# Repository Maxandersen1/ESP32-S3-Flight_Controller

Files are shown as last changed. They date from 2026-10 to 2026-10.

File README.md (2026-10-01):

# ESP32-S3 Custom Flight Controller

A custom-designed drone flight controller built from the ground up around the ESP32-S3 microcontroller. This project is a work-in-progress, covering everything from custom PCB design in KiCad to low-level sensor drivers and Web Serial 3D visualization.

## Hardware Features
- **Microcontroller**: ESP32-S3
- **IMU**: Bosch BMI088 (6-axis accelerometer & gyroscope) via SPI
- **Barometer**: Bosch BMP388 via I2C
- **PCB**: Custom designed in KiCad, hand-soldered SMD components.

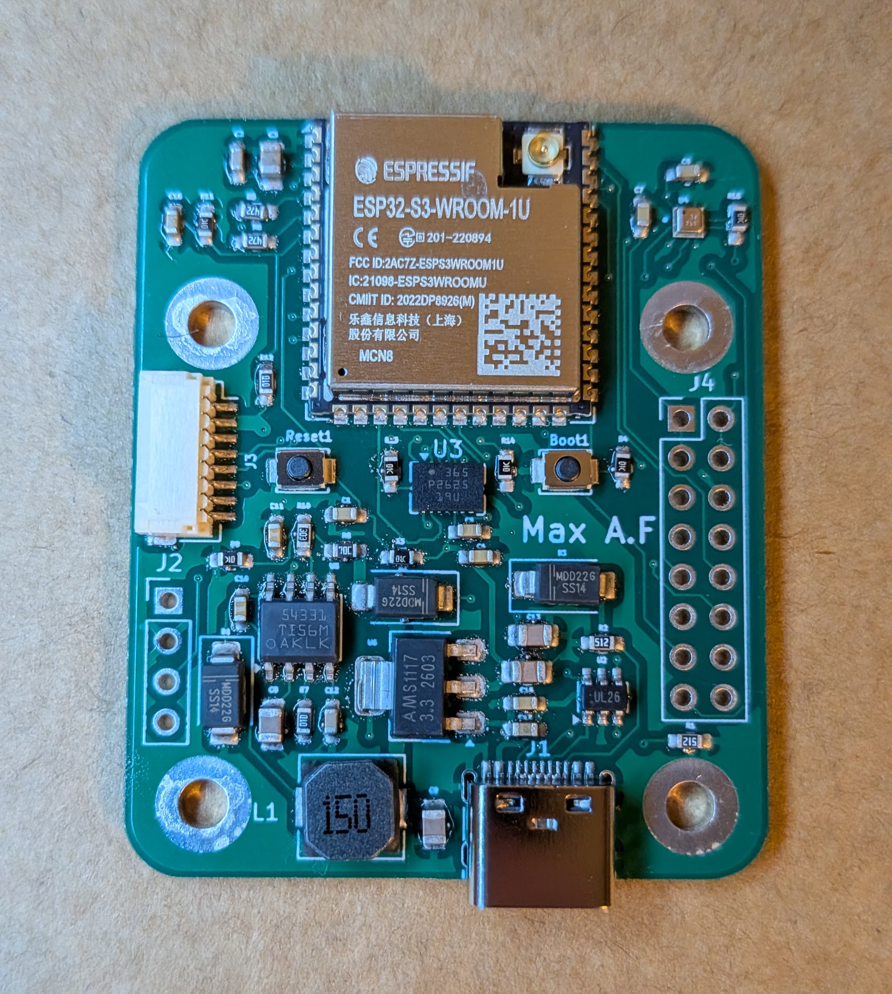
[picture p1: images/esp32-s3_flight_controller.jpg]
Mitt kretskort


## Software / Firmware
The firmware is written in C++ (Arduino framework) and features:
- **Raw SPI Communication**: Bypasses bloated libraries to communicate directly with the BMI088 registers, resolving complex ESP32 HAL macro conflicts.
- **Sensor Fusion**: Implements a custom Complementary Filter combining high-speed gyro data with accelerometer gravity vectors for stable, drift-free Pitch and Roll calculation.
- **Barometric Altimeter**: Features an auto-zeroing routine on startup to establish local ground-level pressure before calculating relative altitude in meters.

## 3D Web Visualizer
Included in the `tools/` directory is a custom HTML5/Three.js 3D drone visualizer. 
It uses the modern **Web Serial API** to connect directly to the flight controller via USB (no servers required) and renders the drone's orientation in real-time at 60fps based on the live IMU telemetry.

## Directory Structure
- `hardware/`: KiCad schematics and PCB layout files.
- `firmware/FlightController/`: The main C++ Arduino sketch containing sensor drivers and mathematical filters.
- `tools/`: Contains `3D_Viewer.html` (Double-click to open in a modern browser).

## Roadmap / To-Do
- [x] PCB Design & Assembly
- [x] I2C & SPI Bring-up
- [x] Raw IMU & Barometer Data Extraction
- [x] Sensor Fusion (Complementary Filter)
- [x] Real-time 3D Visualization
- [ ] PID Controller Implementation
- [ ] ESC Motor Output (DSHOT/PWM)
- [ ] Radio Receiver Integration (ExpressLRS/Crossfire)

*Hardware designed from scratch by Max. Firmware and 3D visualization developed using AI-assisted pair programming.*

## Hardware design process
###Schematic

KiCad Schematic

###PCB-layout

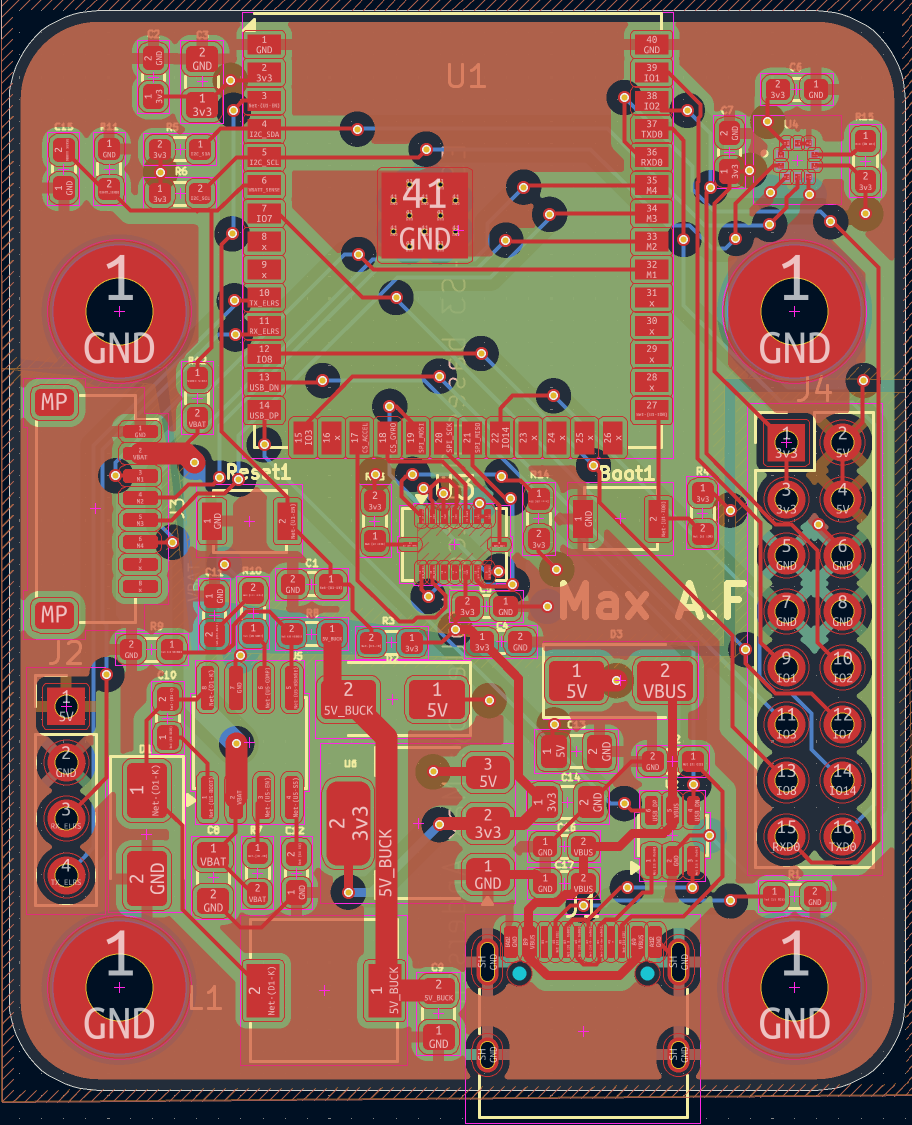
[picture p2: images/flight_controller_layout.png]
KiCad layout


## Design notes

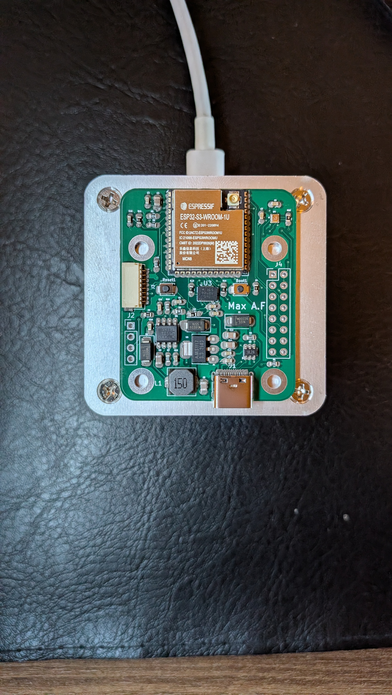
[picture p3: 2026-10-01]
images/hot_plate.jpg

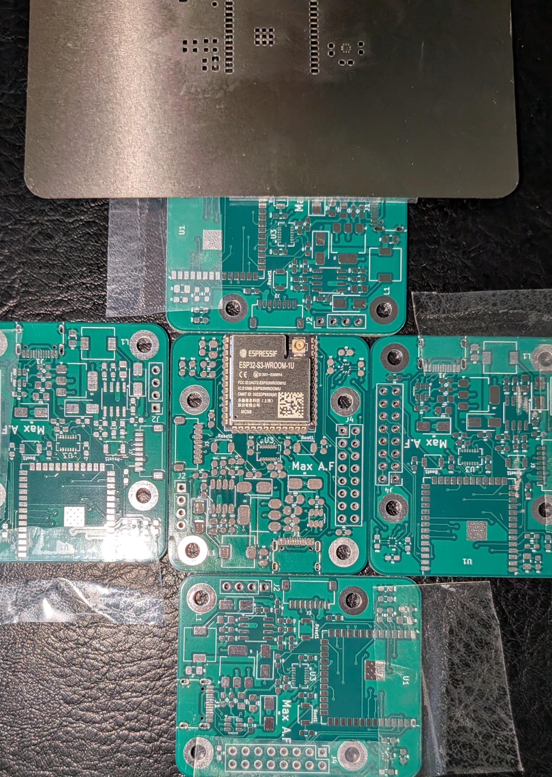
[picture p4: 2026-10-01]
images/esp_added.jpg

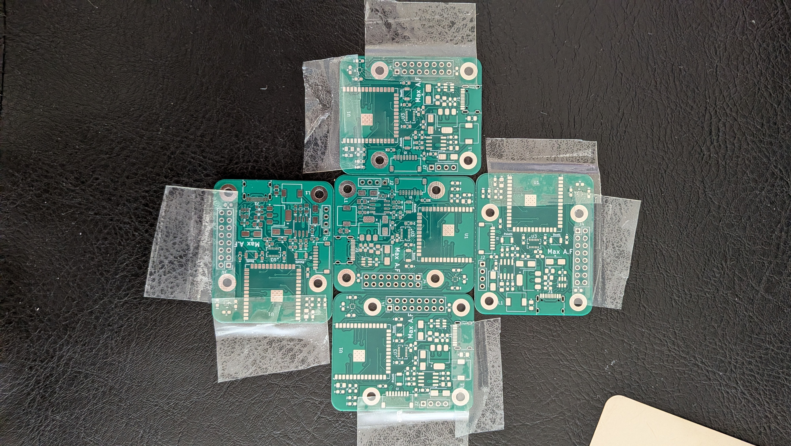
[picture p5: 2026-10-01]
images/taped_pcb.jpg

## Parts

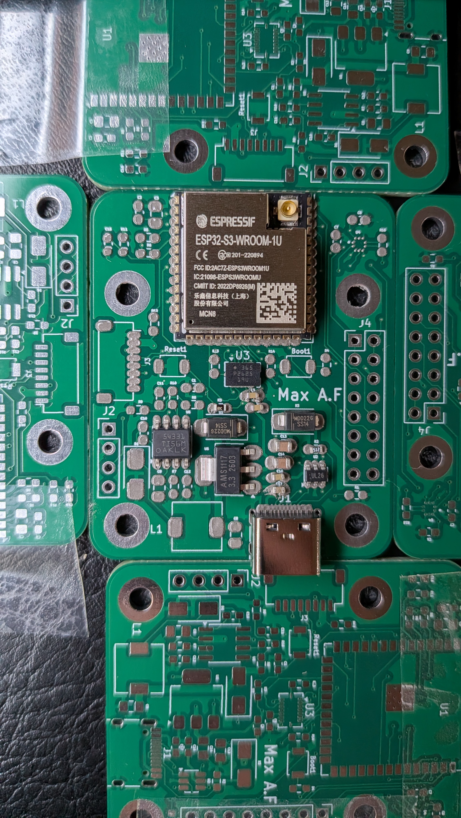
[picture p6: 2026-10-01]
images/components_added1.jpg

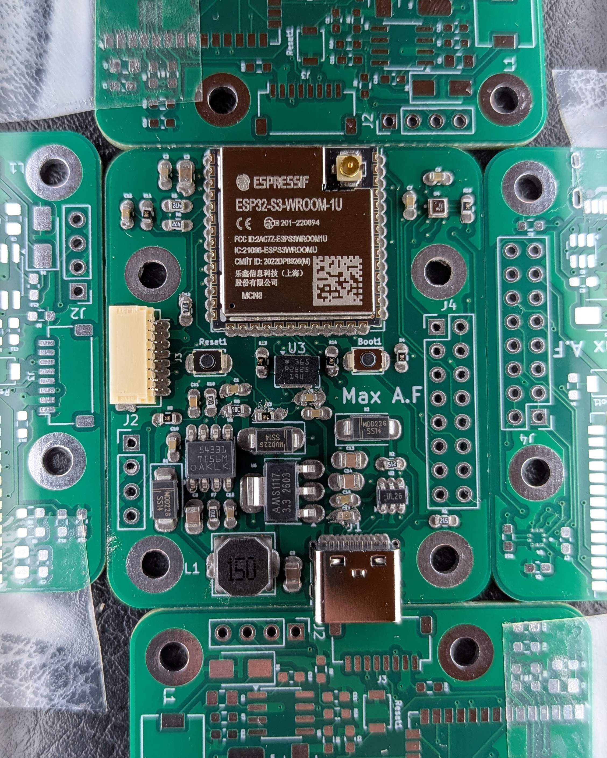
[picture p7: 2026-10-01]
images/all_components_added.jpg

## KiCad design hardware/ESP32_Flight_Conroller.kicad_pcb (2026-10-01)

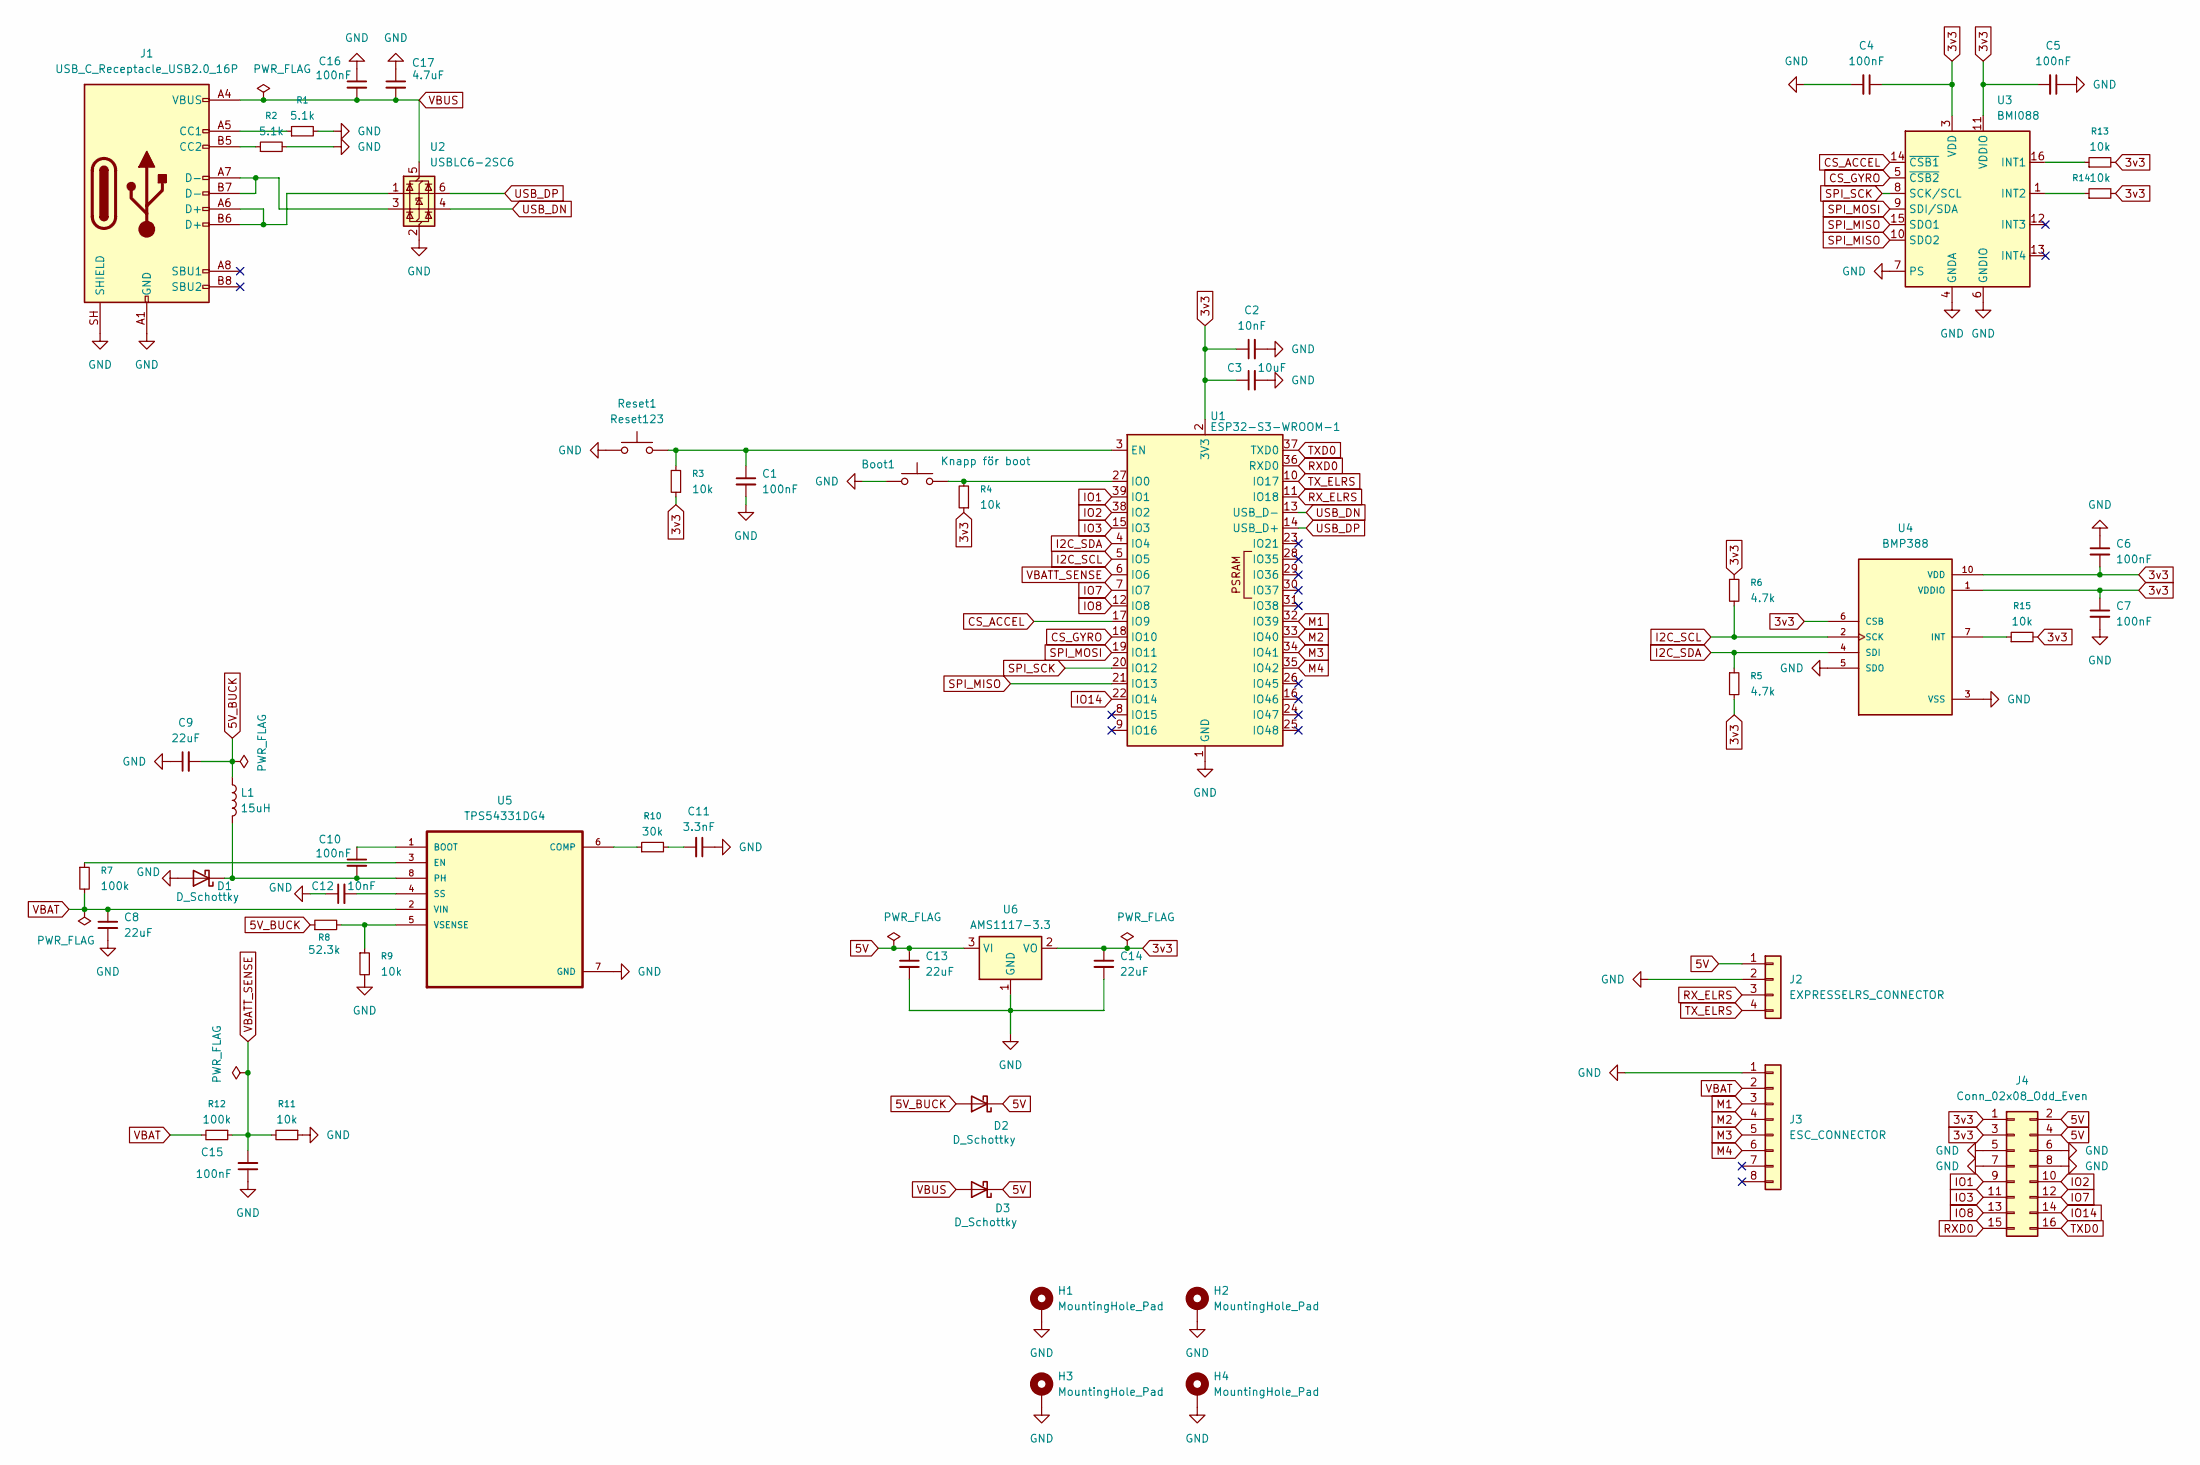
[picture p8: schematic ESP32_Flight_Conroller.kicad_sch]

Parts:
Boot1: Knapp för boot; SW_SPST_B3U-1000P
C1, C4, C5, C6, C7, C10, C15, C16: 100nF; C_0603_1608Metric_Pad1.08x0.95mm_HandSolder
C2, C12: 10nF; C_0603_1608Metric_Pad1.08x0.95mm_HandSolder
C3: 10uF; C_0805_2012Metric_Pad1.18x1.45mm_HandSolder
C8, C9, C13, C14: 22uF; C_0805_2012Metric_Pad1.18x1.45mm_HandSolder
C11: 3.3nF; C_0603_1608Metric_Pad1.08x0.95mm_HandSolder
C17: 4.7uF; C_0603_1608Metric_Pad1.08x0.95mm_HandSolder
D1, D2, D3: D_Schottky; D_SMA
H1, H2, H3, H4: MountingHole_Pad; MountingHole_3mm_Pad
J1: USB_C_Receptacle_USB2.0_16P; USB_C_Receptacle_HRO_TYPE-C-31-M-12
J2: EXPRESSELRS_CONNECTOR; PinHeader_1x04_P2.54mm_Vertical
J3: ESC_CONNECTOR; JST_SH_SM08B-SRSS-TB_1x08-1MP_P1.00mm_Horizontal
J4: Conn_02x08_Odd_Even; PinHeader_2x08_P2.54mm_Vertical
L1: 15uH; L_6.3x6.3_H3
R1, R2: 5.1k; R_0603_1608Metric_Pad0.98x0.95mm_HandSolder
R3, R4, R9, R11, R13, R14, R15: 10k; R_0603_1608Metric_Pad0.98x0.95mm_HandSolder
R5, R6: 4.7k; R_0603_1608Metric_Pad0.98x0.95mm_HandSolder
R7, R12: 100k; R_0603_1608Metric_Pad0.98x0.95mm_HandSolder
R8: 52.3k; R_0603_1608Metric_Pad0.98x0.95mm_HandSolder
R10: 30k; R_0603_1608Metric_Pad0.98x0.95mm_HandSolder
Reset1: Reset123; SW_SPST_B3U-1000P
U1: ESP32-S3-WROOM-1; ESP32-S3-WROOM-1U
U2: USBLC6-2SC6; SOT-23-6
U3: BMI088; Bosch_LGA-16_4.5x3mm_P0.5mm_LayoutBorder7x1y_ClockwisePinNu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
U4: BMP388; XDCR_BMP388; PARTREV 1.7
U5: TPS54331DG4; SOIC-8_3.9x4.9mm_P1.27mm
U6: AMS1117-3.3; SOT-223-3_TabPin2

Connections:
3v3: C2.1, C3.1, C4.1, C5.2, C6.2, C7.1, C14.1, J4.1, J4.3, R3.1, R4.1, R5.2, R6.1, R13.2, R14.2, R15.2, U1.2 (3V3), U3.3 (VDD), U3.11 (VDDIO), U4.1 (VDDIO), U4.6 (CSB), U4.10 (VDD), U6.2 (VO)
5V: C13.1, D2.1 (K), D3.1 (K), J2.1, J4.2, J4.4, U6.3 (VI)
5V_BUCK: C9.2, D2.2 (A), L1.1, R8.1
CS_ACCEL: U1.17 (IO9), U3.14 (~CSB1)
CS_GYRO: U1.18 (IO10), U3.5 (~CSB2)
GND: Boot1.1, C1.2, C2.2, C3.2, C4.2, C5.1, C6.1, C7.2, C8.2, C9.1, C11.1, C12.1, C13.2, C14.2, C15.1, C16.1, C17.1, D1.2 (A), H1.1 (1_1), H2.1 (1_1), H3.1 (1_1), H4.1 (1_1), J1.A1 (GND), J1.A12 (GND), J1.B1 (GND), J1.B12 (GND), J1.SH (SHIELD), J2.2, J3.1, J4.5, J4.6, J4.7, J4.8, R1.2, R2.2, R9.2, R11.1, Reset1.1, U1.1 (GND), U1.40 (GND), U1.41 (GND), U2.2 (GND), U3.2 (GNDA), U3.4 (GNDA), U3.6 (GNDIO), U3.7 (PS), U4.3 (VSS), U4.5 (SDO), U4.8 (VSS), U4.9 (VSS), U5.7 (GND), U6.1 (GND)
I2C_SCL: R6.2, U1.5 (IO5), U4.2 (SCK)
I2C_SDA: R5.1, U1.4 (IO4), U4.4 (SDI)
IO1: J4.9, U1.39 (IO1)
IO2: J4.10, U1.38 (IO2)
IO3: J4.11, U1.15 (IO3)
IO7: J4.12, U1.7 (IO7)
IO8: J4.13, U1.12 (IO8)
IO14: J4.14, U1.22 (IO14)
M1: J3.3, U1.32 (IO39)
M2: J3.4, U1.33 (IO40)
M3: J3.5, U1.34 (IO41)
M4: J3.6, U1.35 (IO42)
unnamed: C11.2, R10.2
unnamed: C10.2, D1.1 (K), L1.2, U5.8 (PH)
unnamed: J1.A5 (CC1), R1.1
unnamed: J1.B5 (CC2), R2.1
unnamed: J1.A6 (D+), J1.B6 (D+), U2.1 (I/O1)
unnamed: J1.A7 (D-), J1.B7 (D-), U2.3 (I/O2)
unnamed: C1.1, R3.2, Reset1.2, U1.3 (EN)
unnamed: Boot1.2, R4.2, U1.27 (IO0)
unnamed: R13.1, U3.16 (INT1)
unnamed: R14.1, U3.1 (INT2)
unnamed: R15.1, U4.7 (INT)
unnamed: C10.1, U5.1 (BOOT)
unnamed: R10.1, U5.6 (COMP)
unnamed: R7.1, U5.3 (EN)
unnamed: C12.2, U5.4 (SS)
unnamed: R8.2, R9.1, U5.5 (VSENSE)
RXD0: J4.15, U1.36 (RXD0)
RX_ELRS: J2.3, U1.11 (IO18)
SPI_MISO: U1.21 (IO13), U3.10 (SDO2), U3.15 (SDO1)
SPI_MOSI: U1.19 (IO11), U3.9 (SDI/SDA)
SPI_SCK: U1.20 (IO12), U3.8 (SCK/SCL)
TXD0: J4.16, U1.37 (TXD0)
TX_ELRS: J2.4, U1.10 (IO17)
USB_DN: U1.13 (USB_D-), U2.4 (I/O2)
USB_DP: U1.14 (USB_D+), U2.6 (I/O1)
VBAT: C8.1, J3.2, R7.2, R12.2, U5.2 (VIN)
VBATT_SENSE: C15.2, R11.2, R12.1, U1.6 (IO6)
VBUS: C16.2, C17.2, D3.2 (A), J1.A4 (VBUS), J1.A9 (VBUS), J1.B4 (VBUS), J1.B9 (VBUS), U2.5 (VBUS)

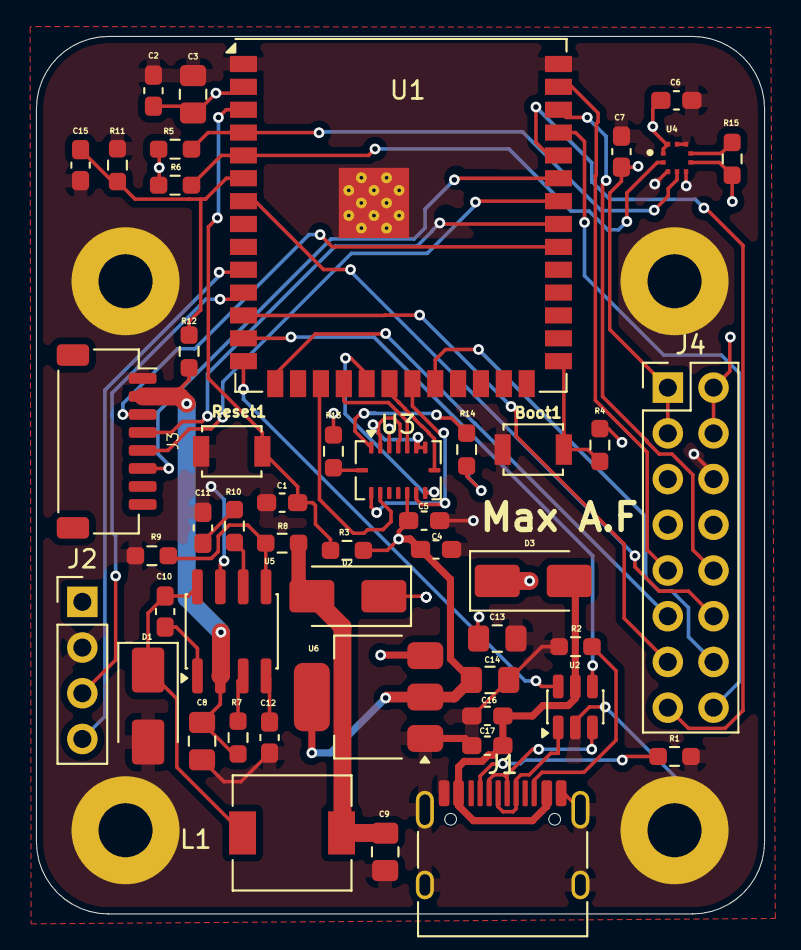
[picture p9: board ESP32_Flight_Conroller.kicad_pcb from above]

Board: 4 copper layers, 40.5 x 48.8 mm, 52 parts (0 on the bottom side), 46 nets.

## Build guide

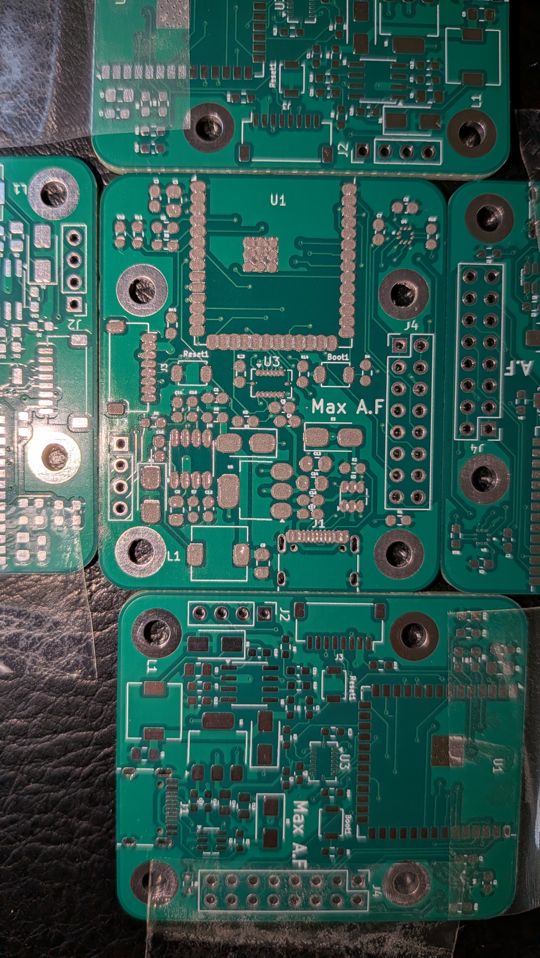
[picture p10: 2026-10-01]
images/solderpaste_pcb.jpg

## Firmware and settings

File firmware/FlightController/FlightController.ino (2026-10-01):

#include <SPI.h>
#include <Wire.h>
#include <math.h>
#include <Adafruit_Sensor.h>
#include "Adafruit_BMP3XX.h"

// --- PINS ---
#define I2C_SDA 4
#define I2C_SCL 5
#define SPI_MOSI 11
#define SPI_MISO 13
#define SPI_SCK  12
#define CS_ACCEL 9
#define CS_GYRO  10

Adafruit_BMP3XX bmp;

void writeSPI(int cs_pin, byte reg, byte value) {
  SPI.beginTransaction(SPISettings(1000000, MSBFIRST, SPI_MODE0));
  digitalWrite(cs_pin, LOW);
  SPI.transfer(reg); 
  SPI.transfer(value);
  digitalWrite(cs_pin, HIGH);
  SPI.endTransaction();
}

float pitch = 0;
float roll = 0;
unsigned long last_time = 0;

float baseline_pressure = 1013.25; 
float current_altitude = 0.0;

void setup() {
  Serial.begin(115200);
  delay(1000);
  
  // Start I2C and Barometer
  Wire.begin(I2C_SDA, I2C_SCL);
  if (bmp.begin_I2C(0x76, &Wire)) {
    bmp.setTemperatureOversampling(BMP3_OVERSAMPLING_8X);
    bmp.setPressureOversampling(BMP3_OVERSAMPLING_4X);
    bmp.setIIRFilterCoeff(BMP3_IIR_FILTER_COEFF_3);
    bmp.setOutputDataRate(BMP3_ODR_50_HZ);

    for(int i=0; i<10; i++) {
       bmp.performReading();
       delay(20);
    }

    float sum_pressure = 0;
    for(int i=0; i<50; i++) {
       bmp.performReading();
       sum_pressure += (bmp.pressure / 100.0); 
       delay(20);
    }
    baseline_pressure = sum_pressure / 50.0;
  }

  // Start IMU
  pinMode(CS_ACCEL, OUTPUT);
  pinMode(CS_GYRO, OUTPUT);
  digitalWrite(CS_ACCEL, HIGH);
  digitalWrite(CS_GYRO, HIGH);
  SPI.begin(SPI_SCK, SPI_MISO, SPI_MOSI, -1);

  writeSPI(CS_ACCEL, 0x7F, 0x00);
  delay(10);
  writeSPI(CS_ACCEL, 0x7D, 0x04);
  delay(50);
  writeSPI(CS_ACCEL, 0x7C, 0x00);
  delay(50);

  last_time = micros();
}

void loop() {
  SPI.beginTransaction(SPISettings(1000000, MSBFIRST, SPI_MODE0));

  // --- LÄS ACCEL ---
  digitalWrite(CS_ACCEL, LOW);
  SPI.transfer(0x12 | 0x80); 
  SPI.transfer(0x00);        
  byte ax_l = SPI.transfer(0x00); byte ax_h = SPI.transfer(0x00);
  byte ay_l = SPI.transfer(0x00); byte ay_h = SPI.transfer(0x00);
  byte az_l = SPI.transfer(0x00); byte az_h = SPI.transfer(0x00);
  digitalWrite(CS_ACCEL, HIGH);

  float acc_x = ((int16_t)((ax_h << 8) | ax_l)) / 10922.0f;
  float acc_y = ((int16_t)((ay_h << 8) | ay_l)) / 10922.0f;
  float acc_z = ((int16_t)((az_h << 8) | az_l)) / 10922.0f;

  // --- LÄS GYRO ---
  digitalWrite(CS_GYRO, LOW);
  SPI.transfer(0x02 | 0x80);
  byte gx_l = SPI.transfer(0x00); byte gx_h = SPI.transfer(0x00);
  byte gy_l = SPI.transfer(0x00); byte gy_h = SPI.transfer(0x00);
  byte gz_l = SPI.transfer(0x00); byte gz_h = SPI.transfer(0x00);
  digitalWrite(CS_GYRO, HIGH);

  float gyr_x = ((int16_t)((gx_h << 8) | gx_l)) / 16.384f;
  float gyr_y = ((int16_t)((gy_h << 8) | gy_l)) / 16.384f;
  float gyr_z = ((int16_t)((gz_h << 8) | gz_l)) / 16.384f;

  SPI.endTransaction();

  // --- Complementary Filter ---
  unsigned long now = micros();
  float dt = (now - last_time) / 1000000.0f; 
  last_time = now;

  float pitch_acc = atan2(acc_x, sqrt(acc_y*acc_y + acc_z*acc_z)) * 180.0 / PI;
  float roll_acc  = atan2(acc_y, sqrt(acc_x*acc_x + acc_z*acc_z)) * 180.0 / PI;

  pitch = 0.98 * (pitch - gyr_y * dt) + 0.02 * pitch_acc;
  roll  = 0.98 * (roll  + gyr_x * dt) + 0.02 * roll_acc;

  // --- LÄS BAROMETERN ---
  if (bmp.performReading()) {
      current_altitude = bmp.readAltitude(baseline_pressure);
  }

  // Serial output for 3D Viewer
  Serial.print(pitch);
  Serial.print(",");
  Serial.print(roll);
  Serial.print(",");
  Serial.println(current_altitude);
  
  delay(10); 
}

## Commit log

2026-10-01 Update README with schematic and PCB layout sections
    Added sections for schematic and PCB layout with images.
2026-10-10 Add assembled PCB section to README
    Added section for assembled PCB with image.
2026-10-10 Enhance hardware design documentation in README
    Updated the README to enhance the hardware design section with detailed descriptions of the schematic and PCB layout.
2026-10-12 Update README: Add Bill of Materials (BOM) & fix formatting
